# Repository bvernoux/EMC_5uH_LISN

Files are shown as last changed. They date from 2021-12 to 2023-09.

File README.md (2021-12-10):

# 5µH LISN(Line Impedance Stabilization Network)
Open Source Hardware Dual 5µH DC LISN with 10dB Attenuator and Transient Limiter for Spectrum Analyzer EMC work.

A LISN is a [Line Impedance Stabilization Network](https://en.wikipedia.org/wiki/Line_Impedance_Stabilization_Network) used in conducted emissions testing.

The AIM of this Dual LISN is to be used for EMC pre-testing with frequency range 30kHz(or lower) to 110MHz(or up to 150MHz or more).

This open source hardware LISN V1 R0 include following features:
* Designed with fully open source tools like [KiCad 5.99 Nightly](https://www.kicad.org)
* Improvement in this design: 
  * Added simulation with LTSpice of the 10dB Attenuator / Transient Filter (with default 1N4148 and BAV99 see Simu dir)
  * Modified Supply & DUT "+ GND -" to be separated by 19.06mm for 4mm BANANA JACK for BNC adapter
  * Use BAV99 instead of 1N4148W Diodes (improve 10dB Attenuator and Transient Limiter to be flat up to >200MHz)
  * Replace Keystone 575-4 by Keystone 575-8 (as the 575-4 was too short)
  * Added more via for better thermal transfer/decoupling around capacitors ...

* Dual LISN in one aluminum box(Hammond 1590B)
  * Maximum current: 5A
  * Nominal operating voltage range: 0V to 60V DC
  * Include 10dB Attenuator and Transient Limiter for each SMA connector to be connected to a Spectrum Analyzer
    * Max. 1W / 30dBm if 50°C Temperature raise is allowed
    * The Transient limiter is a 9kHz HP filter, which is also a dc block.

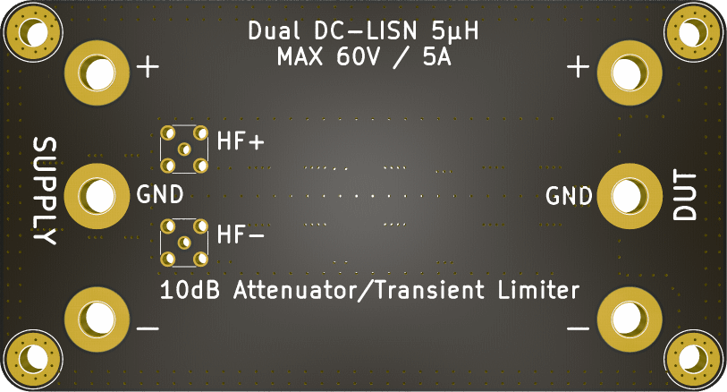
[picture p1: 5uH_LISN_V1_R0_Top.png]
picture of 5uH_LISN_V1_R0_Top

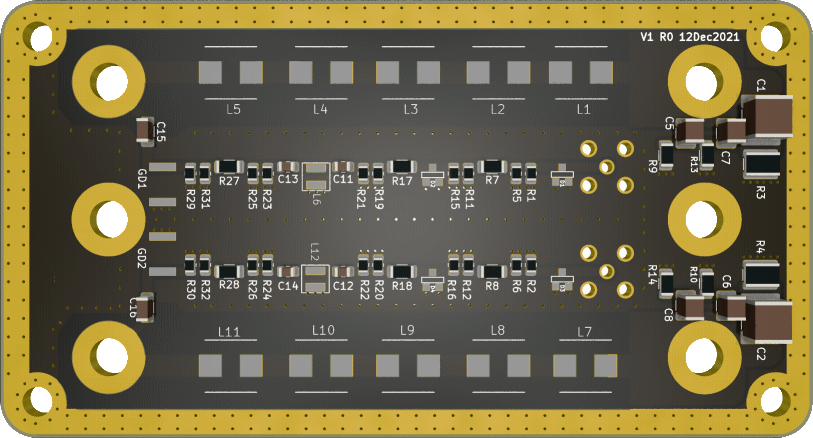
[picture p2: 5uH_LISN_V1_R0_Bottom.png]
picture of 5uH_LISN_V1_R0_Bottom


This work is heavily based on work from others mainly **Jay_Diddy_B** & **Noy** from EEVBLOG forum.

See all links related to the original Dual 5µH LISN:
* https://www.eevblog.com/forum/projects/5uh-lisn-for-spectrum-analyzer-emcemi-work/75/
* https://www.eevblog.com/forum/projects/5uh-lisn-for-spectrum-analyzer-emcemi-work/msg3420102/#msg3420102

Video related to EMC Conducted Emissions / LISN:
* Rohde Schwarz video Understanding LISNs: 
  * This video explains the design and function of a LISN (line impedance stabilization network) and how LISNs are used in conducted EMC testing.
  * https://www.youtube.com/watch?v=QPJzp66Yvzs
* EMC Conducted Emissions: How to connect and set up a LISN:
  * In this video Dr. Ali Shirsavar shows how you can connect and set up a LISN ready for pre-compliance testing of EMC conducted emissions.
  * https://www.youtube.com/watch?v=28oDdL9RnWM

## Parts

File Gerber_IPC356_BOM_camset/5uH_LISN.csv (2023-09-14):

Source: | D:\_\EMC_5uH_LISN\5uH_LISN.kicad_sch
Date: | 14/09/2023 15:15:29
Tool: | Eeschema 7.0.7
Generator: | D:\KiCad\kicad7_0_7\bin\scripting\plugins/bom_csv_grouped_by_value_with_fp.py
Component Count: | 75
Ref | Qnty | Value | Cmp name | Footprint | Description | Vendor | DNP
C1, C2 | 2 | 22uF | C-Device | Capacitor_SMD:C_2220_5650Metric
C5, C6, C7, C8 | 4 | 2.2uF | C-Device | Capacitor_SMD:C_1210_3225Metric
C11, C12, C13, C14 | 4 | 470nF | C-EUC0805 | Capacitor_SMD:C_0805_2012Metric
C15, C16 | 2 | 100nF | C-EUC1206 | Capacitor_SMD:C_1206_3216Metric
CASE_HAMMOND_1590BBK1 | 1 | ~ | CASE_HAMMOND_1590BBK
D1, D2, D3, D4 | 4 | SOT23-DIODEDUAL | SOT23-DIODEDUAL | 5uH_LISN:SOT23-DIODEDUAL
GD1, GD2 | 2 | S30-A75X | GDT_2pin_correct | 5uH_LISN:S30-A400X | Gas Discharge Tube with 2 Pins
H1, H2, H3, H4 | 4 | MOUNT-PAD-ROUND4.1 | MOUNT-PAD-ROUND4.1 | 5uH_LISN:4,1-PAD
J1, J2 | 2 | Conn_SMA | Conn_Coaxial | Connector_Coaxial:SMA_Wurth_60312002114503_Vertical | coaxial connector (BNC, SMA, SMB, SMC, Cinch/RCA, ...)
J3, J4, J5, J6, J7, J8 | 6 | BANANA_CONN | BANANA_CONN | 5uH_LISN:BANANA_CONN
L1, L2, L3, L4, L5, L7, L8, L9, L10, L11 | 10 | 1.1uH | WE-HCI_7030_7040_7050 | 5uH_LISN:WE-HCI_7030_7040_7050
L6, L12 | 2 | 1mH | INDUCTOR | 5uH_LISN:COILCRAFT_1008PS
R1, R2 | 2 | 909R | R-EU_R0805 | Resistor_SMD:R_0805_2012Metric
R3, R4 | 2 | 1R | R-Device | Resistor_SMD:R_1218_3246Metric
R5, R6 | 2 | 825R | R-EU_R0805 | Resistor_SMD:R_0805_2012Metric
R7, R8 | 2 | 12.1R | R-EU_R0805 | Resistor_SMD:R_1206_3216Metric
R9, R10, R13, R14 | 4 | 0R | R-Device | Resistor_SMD:R_1206_3216Metric
R11, R12 | 2 | 243R | R-EU_R0805 | Resistor_SMD:R_0805_2012Metric
R15, R16 | 2 | 274R | R-EU_R0805 | Resistor_SMD:R_0805_2012Metric
R17, R18 | 2 | 30.1R | R-EU_R0805 | Resistor_SMD:R_1206_3216Metric
R19, R20, R21, R22, R23, R24, R25, R26 | 8 | 432R | R-EU_R0805 | Resistor_SMD:R_0805_2012Metric
R27, R28 | 2 | 18.2R | R-EU_R0805 | Resistor_SMD:R_1206_3216Metric
R29, R30 | 2 | 562R | R-EU_R0805 | Resistor_SMD:R_0805_2012Metric
R31, R32 | 2 | 619R | R-EU_R0805 | Resistor_SMD:R_0805_2012Metric

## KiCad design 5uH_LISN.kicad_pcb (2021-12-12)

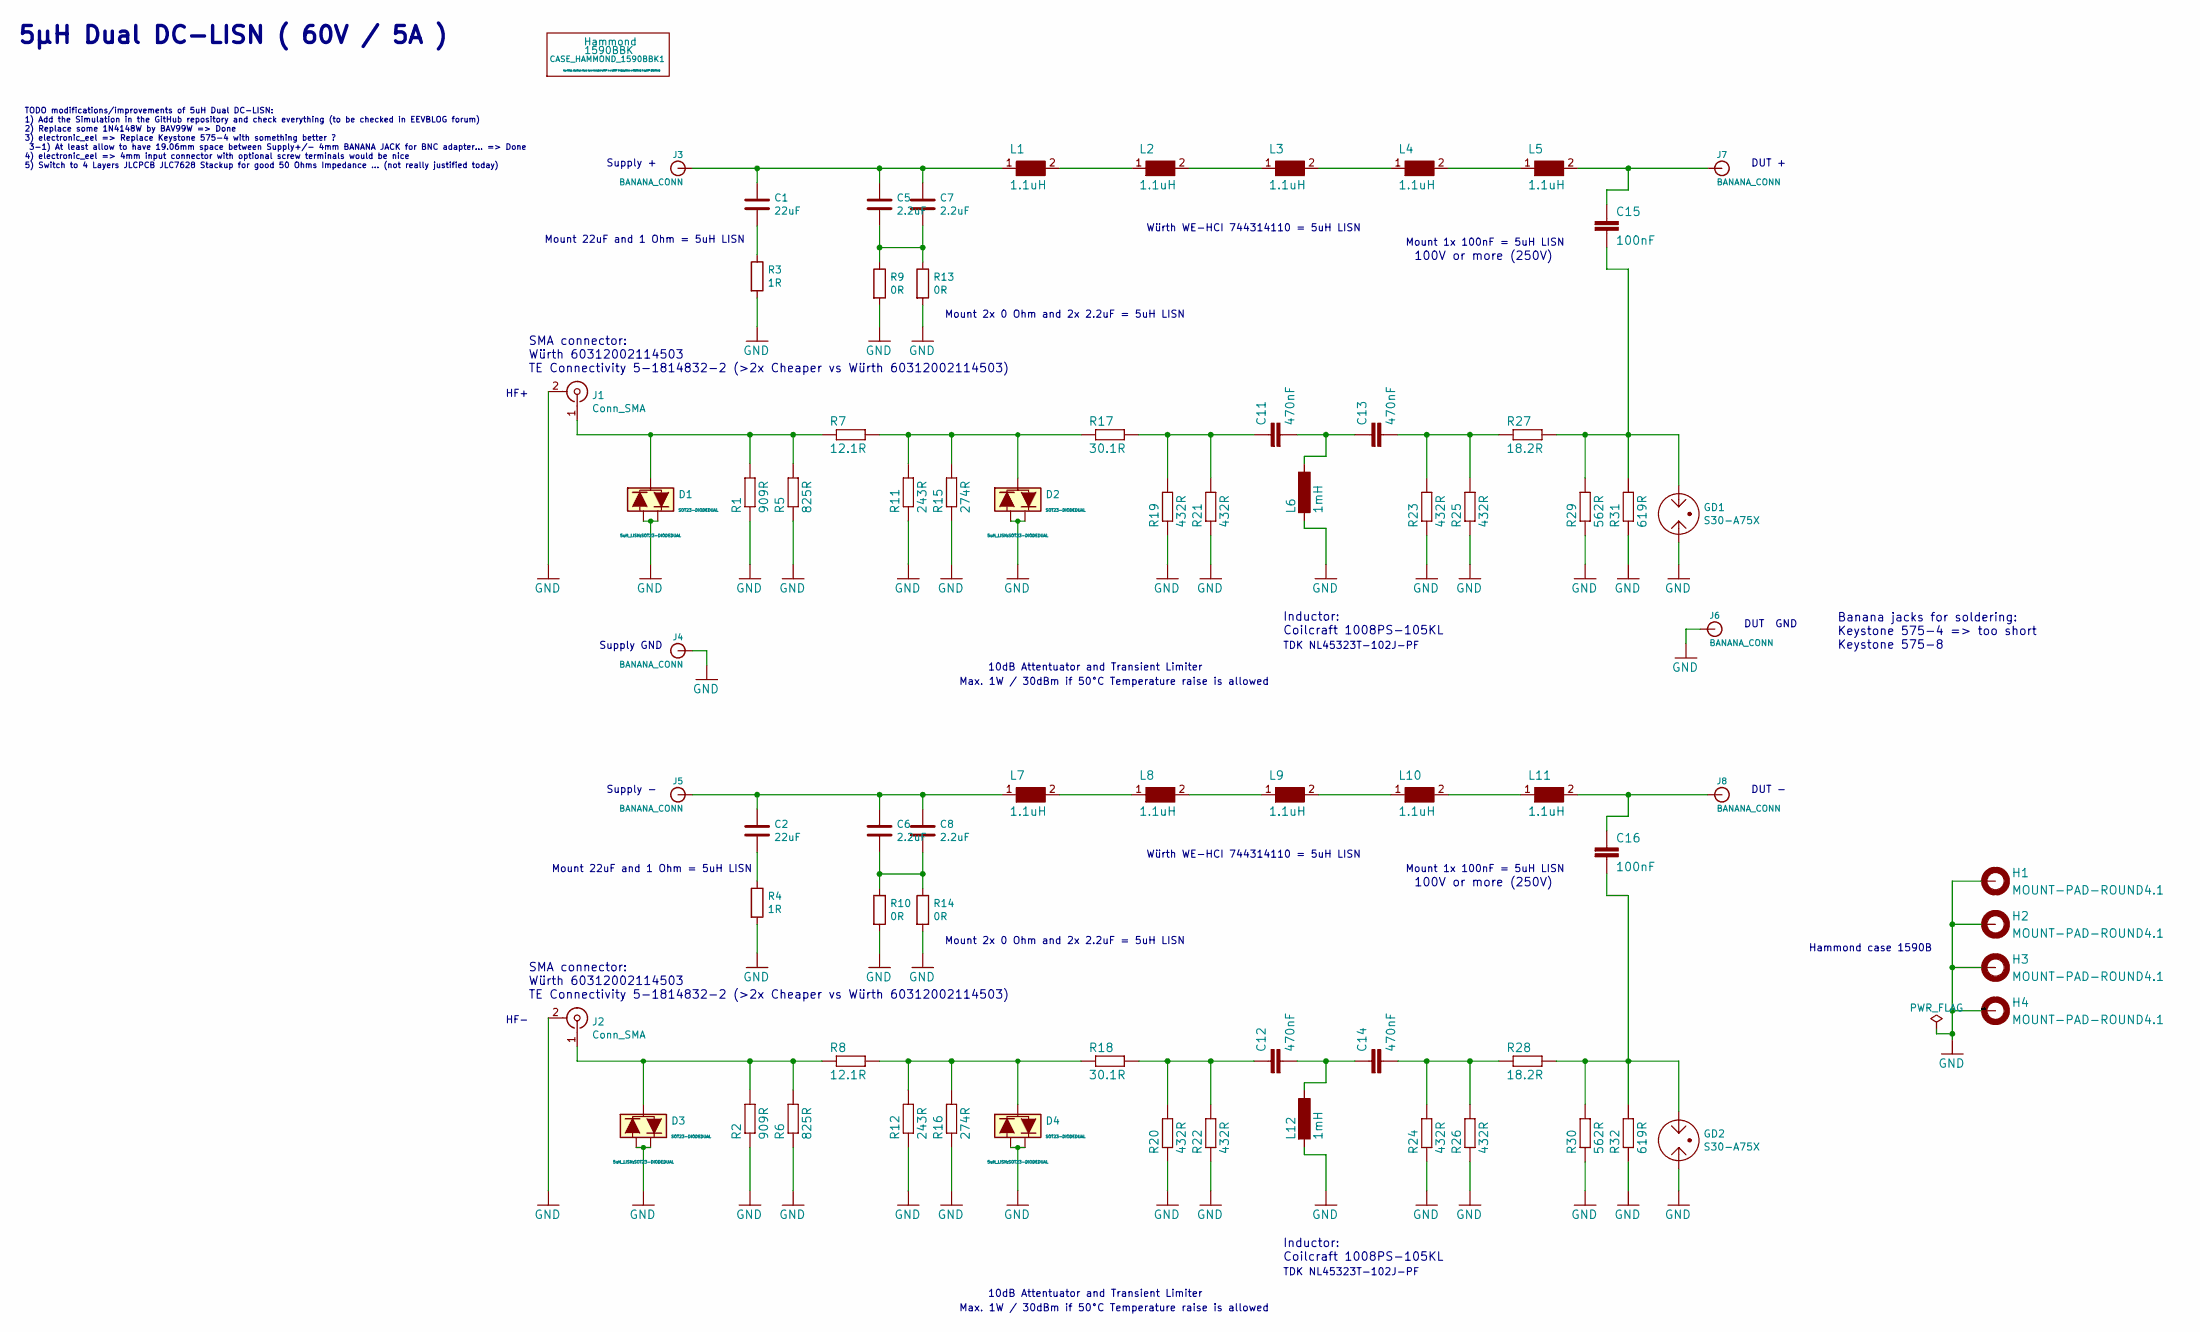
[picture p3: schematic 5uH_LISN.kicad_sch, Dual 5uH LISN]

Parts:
C1, C2: 22uF; C_2220_5650Metric
C5, C6, C7, C8: 2.2uF; C_1210_3225Metric
C11, C12, C13, C14: 470nF; C_0805_2012Metric
C15, C16: 100nF; C_1206_3216Metric
CASE_HAMMOND_1590BBK1: (no value)
D1, D2, D3, D4: SOT23-DIODEDUAL; LCSC C2500
GD1, GD2: S30-A75X; S30-A400X
H1, H2, H3, H4: MOUNT-PAD-ROUND4.1; 4,1-PAD
J1, J2: Conn_SMA; SMA_Wurth_60312002114503_Vertical
J3, J4, J5, J6, J7, J8: BANANA_CONN
L1, L2, L3, L4, L5, L7, L8, L9, L10, L11: 1.1uH; WE-HCI_7030_7040_7050
L6, L12: 1mH; COILCRAFT_1008PS
R1, R2: 909R; R_0805_2012Metric
R3, R4: 1R; R_1218_3246Metric
R5, R6: 825R; R_0805_2012Metric
R7, R8: 12.1R; R_1206_3216Metric
R9, R10, R13, R14: 0R; R_1206_3216Metric
R11, R12: 243R; R_0805_2012Metric
R15, R16: 274R; R_0805_2012Metric
R17, R18: 30.1R; R_1206_3216Metric
R19, R20, R21, R22, R23, R24, R25, R26: 432R; R_0805_2012Metric
R27, R28: 18.2R; R_1206_3216Metric
R29, R30: 562R; R_0805_2012Metric
R31, R32: 619R; R_0805_2012Metric

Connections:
GND: D1.1, D1.2, D2.1, D2.2, D3.1, D3.2, D4.1, D4.2, GD1.1, GD2.1, H1.B4,1 (MOUNT), H2.B4,1 (MOUNT), H3.B4,1 (MOUNT), H4.B4,1 (MOUNT), J1.2 (Ext), J2.2 (Ext), J4.P$1 (1), J6.P$1 (1), L6.P$2 (2), L12.P$2 (2), R1.1, R2.1, R3.2, R4.2, R5.1, R6.1, R9.2, R10.2, R11.1, R12.1, R13.2, R14.2, R15.1, R16.1, R19.1, R20.1, R21.1, R22.1, R23.1, R24.1, R25.1, R26.1, R29.1, R30.1, R31.1, R32.1
unnamed: C1.1, C5.1, C7.1, J3.P$1 (1), L1.1
unnamed: C1.2, R3.1
unnamed: C2.1, C6.1, C8.1, J5.P$1 (1), L7.1
unnamed: C2.2, R4.1
unnamed: C5.2, C7.2, R9.1, R13.1
unnamed: C6.2, C8.2, R10.1, R14.1
unnamed: C11.1, R17.2, R19.2, R21.2
unnamed: C11.2, C13.1, L6.P$1 (1)
unnamed: C12.1, R18.2, R20.2, R22.2
unnamed: C12.2, C14.1, L12.P$1 (1)
unnamed: C13.2, R23.2, R25.2, R27.1
unnamed: C14.2, R24.2, R26.2, R28.1
unnamed: C15.1, J7.P$1 (1), L5.2
unnamed: C15.2, GD1.2, R27.2, R29.2, R31.2
unnamed: C16.1, J8.P$1 (1), L11.2
unnamed: C16.2, GD2.2, R28.2, R30.2, R32.2
unnamed: D1.3, J1.1 (In), R1.2, R5.2, R7.1
unnamed: D2.3, R7.2, R11.2, R15.2, R17.1
unnamed: D3.3, J2.1 (In), R2.2, R6.2, R8.1
unnamed: D4.3, R8.2, R12.2, R16.2, R18.1
unnamed: L1.2, L2.1
unnamed: L2.2, L3.1
unnamed: L3.2, L4.1
unnamed: L4.2, L5.1
unnamed: L7.2, L8.1
unnamed: L8.2, L9.1
unnamed: L9.2, L10.1
unnamed: L10.2, L11.1

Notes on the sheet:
10dB Attentuator and Transient Limiter
Inductor: Coilcraft 1008PS-105KL
Supply -
100V or more (250V)
SMA connector: Würth 60312002114503 TE Connectivity 5-1814832-2 (>2x Cheaper vs Würth 60312002114503)
Max. 1W / 30dBm if 50°C Temperature raise is allowed
Würth WE-HCI 744314110 = 5uH LISN
Mount 1x 100nF = 5uH LISN
5µH Dual DC-LISN ( 60V / 5A )
Mount 22uF and 1 Ohm = 5uH LISN
TDK NL45323T-102J-PF
DUT +
Supply +
DUT GND
Mount 2x 0 Ohm and 2x 2.2uF = 5uH LISN
Hammond case 1590B
TODO modifications/improvements of 5uH Dual DC-LISN: 1) Add the Simulation in the GitHub repository and check everything (to be checked in EEVBLOG forum) 2) Replace some 1N4148W by BAV99W => Done 3) electronic_eel => Replace Keystone 575-4 with something better ? 3-1) At least allow to have 19.06mm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
Banana jacks for soldering: Keystone 575-4 => too short Keystone 575-8
Supply GND
HF-
HF+
DUT -

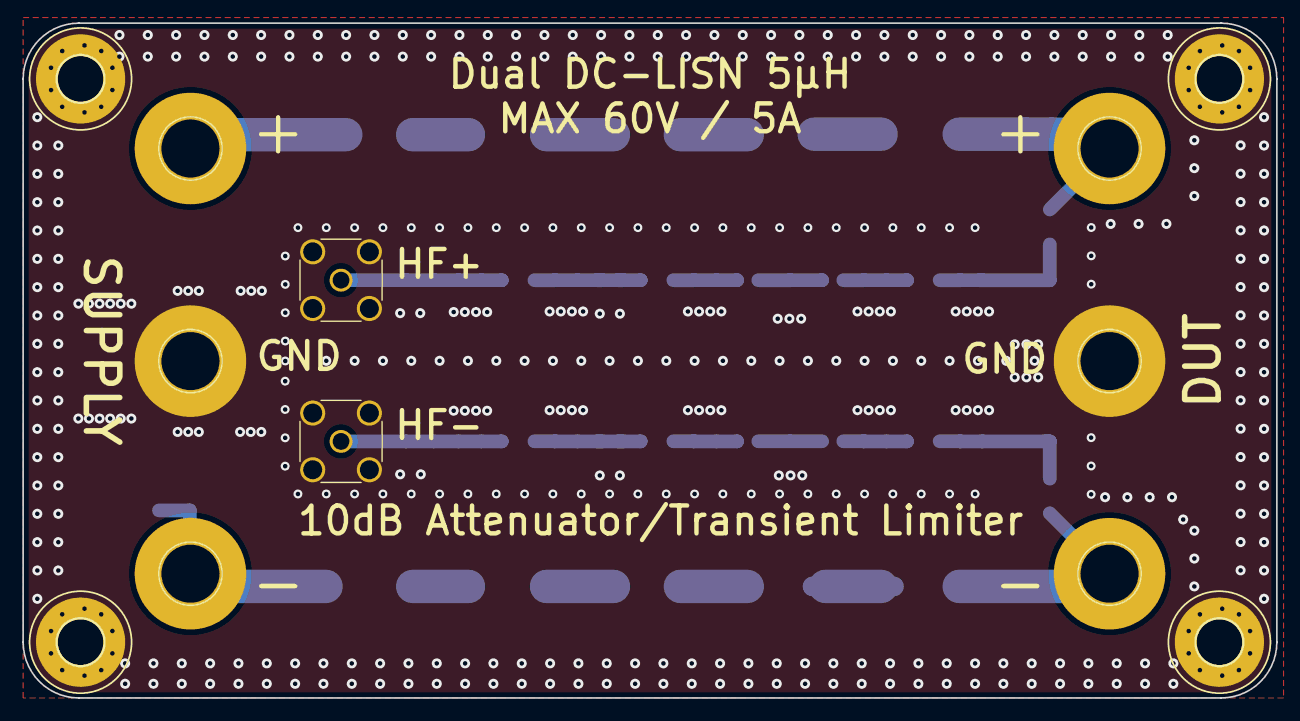
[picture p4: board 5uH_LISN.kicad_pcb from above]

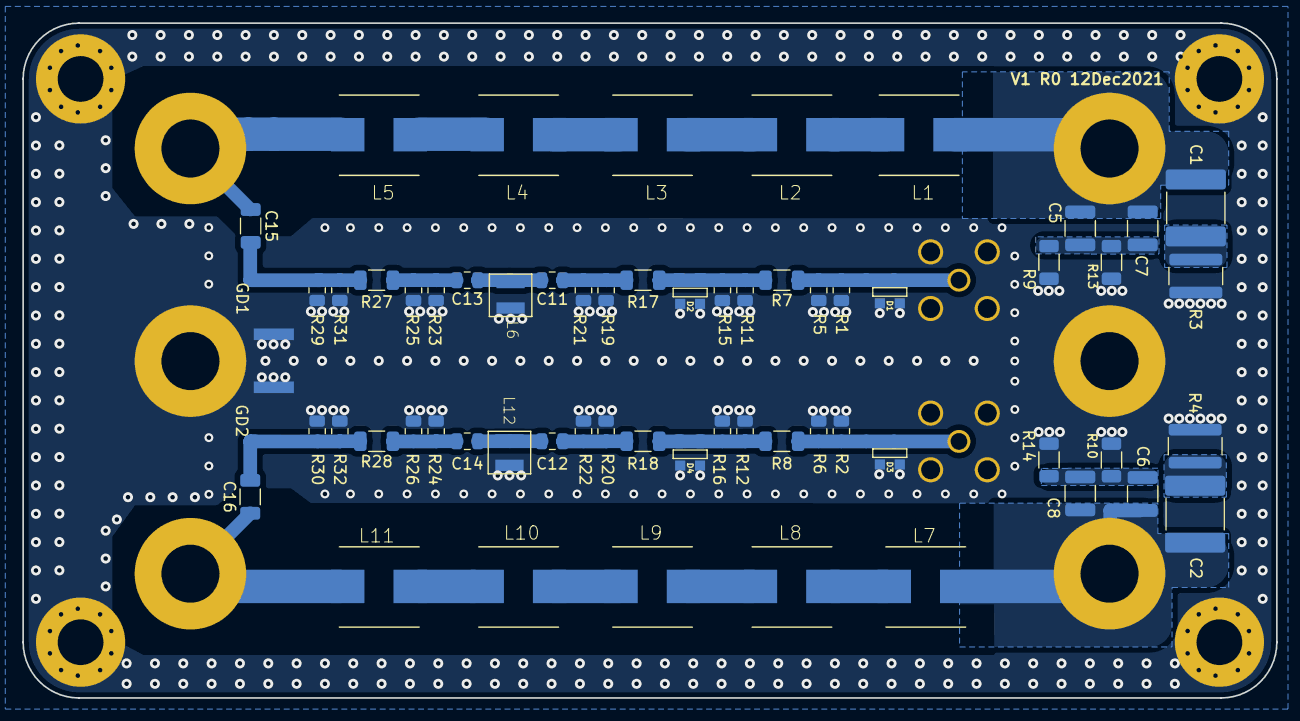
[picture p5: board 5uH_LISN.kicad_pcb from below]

Board: 2 copper layers, 112.4 x 60.5 mm, 74 parts (62 on the bottom side), 29 nets.

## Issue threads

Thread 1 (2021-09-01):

TODO/Ideas modifications/improvements of 5uH LISN

bvernoux, 2021-09-01:
1) Add the Simulation in the GitHub repository and check everything (to be checked in EEVBLOG forum)
2) electronic_eel => Replace some 1N4148W by BAV99 to be checked
3) electronic_eel => Replace Keystone 575-4 with something better ?
 3-1) At least allow to have 19mm space between Supply+/- 4mm BANANA JACK for BNC adapter...
4) electronic_eel => 4mm input connector with optional screw terminals would be nice
5) Switch to 4 Layers JLCPCB JLC7628 Stackup for good 50 Ohms Impedance ...
6) Check if S30-A75X => GDT 75V 5KA 2 POLE SURFACE MOUNT is required for 5uH DC-LISN
7) TBD ...

wm93, 2021-12-08:
Regarding 8. you might consider the following inductors?
- WE 7447720010
(1uH, Fres=195MHz, 6.9Adc 15Asat, THT, 10pc: 0,644 € each) ->[Mouser](https://www.mouser.de/ProductDetail/Wurth-Elektronik/7447720010?qs=sPbYRqrBIVnpxnA1X%252BwmqA%3D%3D)

- Bourns RLB9012-1R0ML
(1uH, Fres=150MHz, 10Adc, THT, 10pc: 0,561€ each) -> [Mouser](https://www.mouser.de/ProductDetail/Bourns/RLB9012-1R0ML?qs=dB0LedT%252BmmABces9278Nbg%3D%3D)

- Coilcraft SER2009-102MLD (more expensive but much higher dc current + self-resonance)
(1uH, Fres=488MHz, 54Adc, 29Asat, SMD, 10pc: 2,31€ each) -> [Mouser](https://www.mouser.de/ProductDetail/Coilcraft/SER2009-102MLD?qs=zCSbvcPd3pab%252BkLHUUwP3w%3D%3D)

bvernoux, 2021-12-10:
Thanks for the feedback and references
My remarks:
- Würth WE 7447720010 is similar in size to Würth WE-HCI 744314110 but will requires PCB change as it is through hole
  - Potentially we can do 1 footprint to use WE 7447720010 or Würth WE-HCI 744314110
  - The biggest advantage is the price is >4.5x lower vs Würth WE-HCI 744314110 (I will buy few to test them)
- Bourns RLB9012-1R0ML is similar in size (9mm x 9mm x 12.2mm) to Würth WE-HCI 744314110 but will requires PCB change as it is through hole
  - Potentially we can do 1 footprint to use Würth WE 7447720010 or Würth WE-HCI 744314110 or Bourns RLB9012-1R0ML
  - The biggest advantage is the price is >4x lower vs Würth WE-HCI 744314110 (I will buy few to test them)
- Coilcraft SER2009-102MLD is very big (18.7mm x 19.18mm x 8.64mm vs Würth WE-HCI 744314110=7mm x 6.9mm x 4.8mm) and will requires change of the PCB (I cannot test such big Inductor on actual PCB as maximum we can place 12mm Inductors)
  - It is very interesting if user's need to increase the max power which is limited today to 5A

For information:
I have launched a production of 5 boards with a new version (called V1 R0) of actual design (that I will push on github soon) including following improvements:
- Added simulation with LTSpice of the 10dB Attenuator / Transient Filter
- Replaced some 1N4148W by BAV99W (to reach up to 400MHz flat 10dB Attenuator / Transient Filter)
- Changed space to have 19.06mm between Supply / DUT "+" <=> "GND" <=> "-" => 4mm BANANA JACK for BNC adapter

wm93, 2021-12-10:
Hey, thanks for your quick reply :)
I did also some simulations and overlayed them in a graph with the CISPR16/CISPR25 given Impedanze/Phase graphs for the 5uH ANs.

Since you started the project, where would you like me to post that information (if at all)? Do you want to work here in the repo or should I post those discussions in the EEVblog thread you mentioned in the readme?

bvernoux, 2021-12-10:
I have just pushed the version V1 R0
You can do a Pull Request and add your simulation in Simu directory (please use LTSpice and or only open source/free tool for simulation)

wm93, 2021-12-11:
Should we do some proper folder structure? E.g.

master
- readme.md
- KiCAD
- Simulation
  - 10dBAttenuator_TransientLimiter
    - 10dBAttenuator_TransientLimiter.asc
    - 10dBAttenuator_TransientLimiter_BAV99.asc
    - BAV99.mod
  - CISPR16_5uH_LISN
  - CISPR25_5uH_LISN
  - ...
- Documentation

For example, I did a simulation and plotted it together with the CISPR given impedances/phases of the 5uH LISN. I would like to document that somewhere.
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

bvernoux, 2021-12-11:
Yes if there is lot of simulation it is better to have a folder structure like in your proposal (so far I have done only 10dBAttenuator_TransientLimiter but other simulation are welcome)

wm93, 2021-12-12:
Do I need to get access rights to the repository, before I can do changes? Tried to "git mv Simu Simulation; git commit; git push" but it wont let me do it.

bvernoux, 2021-12-12:
If you want to contribute you shall work on your own fork of this repository, then do a Pull Request to this one and I will check everything ... and merge it if all is ok

Brianwongjie, 2023-07-05:
Hello, I found your Github website from the eevblog, but I couldn't find the original design information about 50uh Lisn in the entire forum. I would like to inquire if there are any BOMs or Gerber related to saving 50uh Lisn here

bvernoux, 2023-07-06:
> Hello, I found your Github website from the eevblog, but I couldn't find the original design information about 50uh Lisn in the entire forum. I would like to inquire if there are any BOMs or Gerber related to saving 50uh Lisn here

The purpose of this Repository is to only work on EMC 5uH LISN (low voltage) and it is not planned to add the 50uH LISN as I do not have usage of such higher voltage LISN which can be lethal (see https://www.quora.com/What-is-the-safe-limit-of-DC-voltage-for-humans-to-touch) if not used correctly.

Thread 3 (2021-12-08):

Redesign housing for CISPR25 conform measurement setup?

wm93, 2021-12-08:
According to CISPR25:2016, 6.3.2 Test setup / 6.3.2.1 Location of EUT, the EUT shall be placed on a non-conductive, low relative permittivity material (epsilon_r <= 1.4) at **50mm +/-5mm** above the reference ground plane (RGP). In 6.3.2.2 Location of the test harness, the length of 200mm (+200mm) power supply lines with a distance of **50mm +/-5mm** from the RGP is specified.

To get a measurement setup closer to the CISPR25 standard, I recommend to change housing from Hammond 1590B to the Tekbox TBOH01 specified housing Hammond 1550DBK or 1550D. That way you could mount the binding posts at 50mm height on the sides of the Box, similar to the Tekbox LISN.

bvernoux, 2021-12-10:
Thanks for your feedback it is interesting to "quote" that reference to be more compliant with CISPR25:2016 specification.
The drawback is this case is very ugly and big in comparison it will be interesting to compare results with both cases too as I really doubt there is lot of change.

bvernoux, 2021-12-10:
References Hammond 1550DBK or 1550D to be added as option in future version of the design (mainly schematic/BOM as that does not change the PCB)

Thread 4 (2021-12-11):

Remove bottom layer soldermask on PCB edge for proper grounding to case

wm93, 2021-12-11:
Read through the [EEVblog thread regarding the LISN](https://www.eevblog.com/forum/projects/5uh-lisn-for-spectrum-analyzer-emcemi-work/102/) and noticed, that the current layout is missing the soldermask keepout on PCB edge for a proper grounding to the Hammond 1590B case.

Was this intentional or does it require a fix?

bvernoux, 2021-12-11:
Yes it requires to add a mask for better grounding of the case with the PCB on Bottom layer

bvernoux, 2021-12-12:
@wm93 tell me if you see something to improve else we can close this issue

Closed 2021-12-12.

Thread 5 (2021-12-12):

Add selectable 50Ohm termination via switch?

wm93, 2021-12-12:
During CE measurements using dual LISNs, you measure power supply +/- lines separatly, while terminating the other SA port with 50Ohm.

Does it make sense to integrate such termination on the "unused" port via a 3-way switch?

Switch positions would be:
1. 50Ohm termination on HF+
2. No Termination --> For connecting a LISN Mate (Measuring CM noise)
3. 50Ohm termination on HF -

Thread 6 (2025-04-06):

Do you have any exact BOM to order?

omarKmekkawy, 2025-04-06:
Hello,

Thank you for the project. I am wondering if you have any BOM with exact components to order.

Thank you,
BR,

bvernoux, 2025-04-07:
The BOM details is available in schematics BOM which can be see with KiCad
See the LibreOffice Calc document in attachment too (which is just an extract of the KiCad BOM)

[5uH_LISN_BOM.ods](https://github.com/user-attachments/files/19627651/5uH_LISN_BOM.ods)

Closed 2025-04-07.

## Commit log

2021-09-01 First Import KiCad 6 open source hardware 5uH Dual LISN based on work from Jay_Diddy_B & Noy from EEVBLOG forum.
    [5uH_LISN.kicad_pcb, 5uH_LISN.kicad_sch]
2021-12-10 LISN V1 R0 * Added simulation with LTSpice of the 10dB Attenuator / Transient Filter (with default 1N4148 and BAV99) * Replaced some 1N4148W by BAV99 from Nexperia (to reach up to 400MHz flat 10dB At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
    [5uH_LISN.kicad_pcb, 5uH_LISN.kicad_sch]
2021-12-10 LISN V1 R0 (pre-release additions) * Add Picture of the PCB Top/Bottom * Add Schematic (5uH_LISN_V1_R0_schematic.pdf)
2021-12-12 Fixed issue https://github.com/bvernoux/EMC_5uH_LISN/issues/4 Remove bottom layer soldermask on PCB edge for proper grounding to case
    [5uH_LISN.kicad_pcb]
2023-09-14 Add directory with Gerber files, IPC356, BOM(csv) and ZofzPCB portable v2.0.1.0 ".camset"
    [5uH_LISN-B_Mask.gbs, 5uH_LISN-B_Paste.gbp, 5uH_LISN-B_Silkscreen.gbo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]
